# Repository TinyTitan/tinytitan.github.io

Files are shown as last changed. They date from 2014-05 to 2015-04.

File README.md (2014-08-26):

### Tiny Titan
Tiny Titan is a sub-$1,000 classroom supercomputer designed to teach aspiring scientists the basics of parallel computing. Unlike modern desktops and laptops that hide parallelism from the user, Tiny Titan makes parallel concepts explicit.

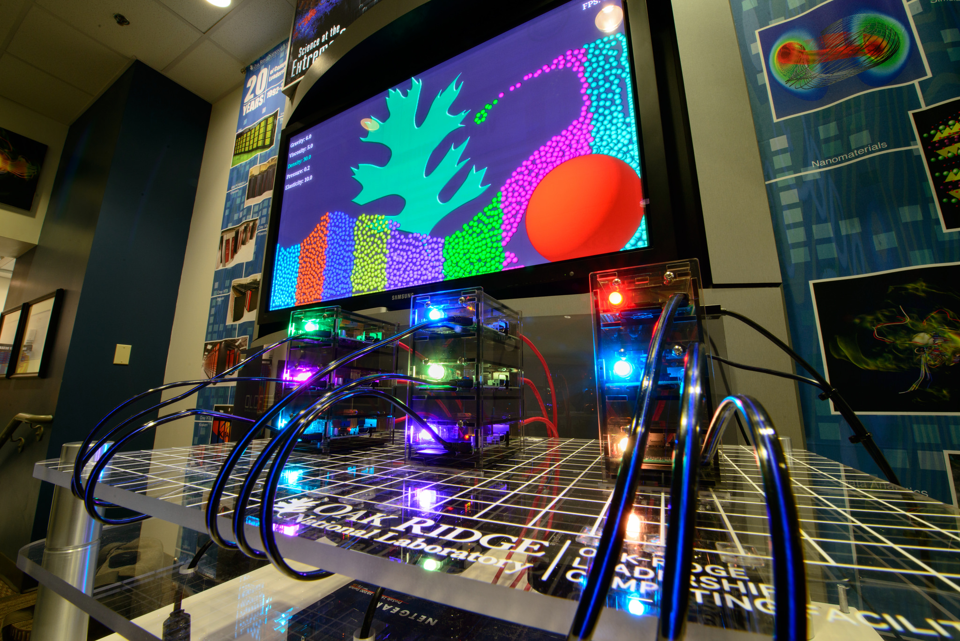
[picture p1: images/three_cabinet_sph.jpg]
SPH


## Software
Tiny Titan features a cornucopia of interactive parallel computing demonstrations and exercises. Some of these are available below:
* [Interactive Fluid Mechanics](https://github.com/TinyTitan/SPH)
* [PiBrot Race](https://github.com/TinyTitan/PiBrot)

## Build your Own
You can build and program your own Tiny Titan using the plans and parts lists available here:

* [9 x RASPBERRY-PI  RASPBERRY-PI/8GB-USD  MODEL B - 8GB SDCard W/ NOOBS PRE-INSTALLED](http://www.newark.com/raspberry-pi/raspberry-pi-8gb-usd/model-b-8gb-sdcard-w-noobs-pre/dp/04X5042)
* [9 x Flowing Effect MicroUSB Data+Charging Cable - Black w/Aqua EL](http://www.adafruit.com/products/1233)
* [9 x 2ft Flat Cat 5 100Mb Ethernet Cable](http://www.newegg.com/Product/Product.aspx?Item=N82E16812422526)
* [1 x Microsoft Xbox 360 Wireless Controller for Windows](http://www.amazon.com/Microsoft-Xbox-Wireless-Controller-Windows/dp/B004QRKWKQ/)
* [1 x BlueRigger High Speed HDMI to DVI Adapter Cable](http://www.amazon.com/BlueRigger-High-Speed-Adapter-Cable/dp/B005LJQO9G/)
* [1 x 18-8 Stainless Steel Socket Cap Screw, Button Head, Internal Hex Drive, Meets ISO 7380, 16mm Length, Fully Threaded, M3-0.5 Metric Coarse Threads (Pack of 100)](http://www.amazon.com/gp/product/B005E00BN2/)
* [1 x Steel Hex Nut, M3-0.5 Threads, Made in US (Pack of 100)](http://www.amazon.com/gp/product/B000NBIH92/)
* [3 x Plugable 7 Port High Speed USB 2.0 Hub with 3A Power Adapter](http://www.amazon.com/gp/product/B003Z4G3I6/)
* [1 x NETGEAR ProSAFE 16-Port Fast Ethernet Desktop Switch (FS116)](http://www.amazon.com/NETGEAR-ProSAFE-16-Port-Ethernet-Desktop/dp/B000063UZW/)

The final part is the laser cut acrylic cabinets. We recommend ordering from [Ponoko](http://www.ponoko.com). They allow you to upload svg files and have materials laser cut. Our design is an upright cabinet version of this [excellent Raspberry Pi Enclosure](http://www.thingiverse.com/thing:25100) by [builttospec](http://www.thingiverse.com/builttospec), and is likewise available under the [CC BY-SA 3.0](http://creativecommons.org/licenses/by-sa/3.0). You can download [SketchUp](http://www.sketchup.com) and [Ponoko](https://www.ponoko.com/) compatible svg files of our model here:

- [tinytitan_assembled_model.skp](http://tinytitan.github.io/downloads/tinytitan_assembled_model.skp)
- [tinytitan_flattened_parts.skp](http://tinytitan.github.io/downloads/tinytitan_flattened_parts.skp)
- [tinytitan_p3_inkscape_fixed.svg](http://tinytitan.github.io/downloads/tinytitan_p3_inkscape_fixed.svg)

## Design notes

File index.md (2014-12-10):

---
layout: page
title: Tiny Titan
description: "A sub-$1,000 classroom supercomputer"
modified: 2014-05-09
tags: [hardware]
image:
  feature: leadership_glamour_shot-2.jpg
  credit: Adam Simpson
  creditlink: http://olcf.ornl.gov
comments: false
share: true
---

Tiny Titan is a $1,000 classroom supercomputer designed to teach aspiring scientists the basics of parallel computing. Unlike modern desktops and laptops that hide parallelism from the user, Tiny Titan makes parallel concepts explicit.

SPH

## Software

Tiny Titan features interactive simulations that showcase the basic concepts of parallel computing. An Xbox controller allows students to explore load-balancing and communication by directing the simulation in real-time. Each of these simulations are freely available on our [GitHub](https://github.com/tinytitan).

## Build your Own

You can build and program your own Tiny Titan using the plans and parts lists available here:

| Quantity&nbsp; | Item |
| :---: | :--- |
| 9 | [Raspberry Pi Model B+ with 8GB Micro SD Card](http://www.newark.com/raspberry-pi/raspberry-modb-8gb-usd/raspberry-pi-model-b-8gb-micro/dp/68X0156) |
| 9 | [Animated Power Cables](http://www.adafruit.com/products/1233) |
| 9 | [USB LED Lights](http://buy.thingm.com/blink1) |
| 3 | [USB Power Hub](http://www.amazon.com/gp/product/B003Z4G3I6/) | 
| 3 | [Stackable Raspberry Pi B+ Case (Base)](http://www.amazon.com/Stackable-Case-Raspberry-Pi-Model/dp/B00M15N06I/) | 
| 6 | [Stackable Raspberry Pi B+ Case (Additional Layer)](http://www.amazon.com/Stackable-Raspberry-Pi-Case-Additional/dp/B00K5JKHUY/) | 
| 2 | [5 pack, 3ft Flat Ethernet Cables](http://www.amazon.com/Cable-Matters-5-Pack-Snagless-Ethernet/dp/B00E5I7UF6/) |
| 1 | [Wireless Microsoft Xbox 360 Controller](http://www.amazon.com/Microsoft-Xbox-Wireless-Controller-Windows/dp/B004QRKWKQ/) |
| 1 | [HDMI to DVI Adapter](http://www.amazon.com/BlueRigger-High-Speed-Adapter-Cable/dp/B005LJQO9G/) |
| 1 | [16-Port Ethernet Switch](http://www.amazon.com/NETGEAR-ProSAFE-16-Port-Ethernet-Desktop/dp/B000063UZW/) |
{: rules="groups"}

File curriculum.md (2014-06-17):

---
layout: page
title: Curriculum
permalink: /curriculum/
description: "An ideal platform for HPC education"
modified: 2013-05-31
category: articles
tags: [sample post]
image:
  feature: IMG_20140507_095849.jpg
comments: true
share: true
---

Comming soon!

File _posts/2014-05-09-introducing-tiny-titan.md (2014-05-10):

---
layout: post
title: Introducing Tiny Titan
description: "Just about everything you'll need to style in the theme: headings, paragraphs, blockquotes, tables, code blocks, and more."
modified: 2014-05-09
tags: [hardware]
image:
  feature: IMG_20140507_095849.jpg
comments: false
share: true
---

Tiny Titan is a sub-$1,000 classroom supercomputer designed to teach aspiring scientists the basics of parallel computing. Unlike modern desktops and laptops that hide parallelism from the user, Tiny Titan makes parallel concepts explicit.

SPH

## Software

Tiny Titan features a cornucopia of interactive parallel computing demonstrations and exercises. Some of these are available below:

* [Interactive Fluid Mechanics](https://github.com/adamsimpson/SPH)
* [PiBrot Race](https://github.com/AdamSimpson/Mandelbrot)

## Build your Own

You can build and program your own Tiny Titan using the plans and parts lists available here:

| Quantity&nbsp; | Item |
| :---: | :--- |
| 9 | [RASPBERRY-PI  RASPBERRY-PI/8GB-USD  MODEL B - 8GB SDCard W/ NOOBS PRE-INSTALLED](http://www.newark.com/raspberry-pi/raspberry-pi-8gb-usd/model-b-8gb-sdcard-w-noobs-pre/dp/04X5042) |
| 9 | [Flowing Effect MicroUSB Data+Charging Cable - Black w/Aqua EL](http://www.adafruit.com/products/1233) |
| 9 | [2ft Flat Cat 5 100Mb Ethernet Cable](http://www.newegg.com/Product/Product.aspx?Item=N82E16812422526) |
| 1 | [Microsoft Xbox 360 Wireless Controller for Windows](http://www.amazon.com/Microsoft-Xbox-Wireless-Controller-Windows/dp/B004QRKWKQ/) |
| 1 | [BlueRigger High Speed HDMI to DVI Adapter Cable](http://www.amazon.com/BlueRigger-High-Speed-Adapter-Cable/dp/B005LJQO9G/) |
| 1 | [18-8 Stainless Steel Socket Cap Screw, Button Head, Internal Hex Drive, Meets ISO 7380, 16mm Length, Fully Threaded, M3-0.5 Metric Coarse Threads (Pack of 100)](http://www.amazon.com/gp/product/B005E00BN2/) |
| 1 | [Steel Hex Nut, M3-0.5 Threads, Made in US (Pack of 100)](http://www.amazon.com/gp/product/B000NBIH92/) |
| 3 | [Plugable 7 Port High Speed USB 2.0 Hub with 3A Power Adapter](http://www.amazon.com/gp/product/B003Z4G3I6/) |
| 1 | [NETGEAR ProSAFE 16-Port Fast Ethernet Desktop Switch (FS116)](http://www.amazon.com/NETGEAR-ProSAFE-16-Port-Ethernet-Desktop/dp/B000063UZW/) |
{: rules="groups"}

The final part is the laser cut acrylic cabinets. We recommend ordering from [Ponoko](http://www.ponoko.com). They allow you to upload svg files and have materials laser cut. Our design, available [here](https://raw.github.com/olcf/tinytitan/master/images/tinytitan_p3_inkscape_fixed.svg), is an upright cabinet version of this [excellent Raspberry Pi Enclosure](http://www.thingiverse.com/thing:25100) by [builttospec](http://www.thingiverse.com/builttospec), and is likewise available under the [CC BY-SA 3.0](http://creativecommons.org/licenses/by-sa/3.0).
Below is just about everything you'll need to style in the theme. Check the source code to see the many embedded elements within paragraphs.

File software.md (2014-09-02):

---
layout: page
title: Software Setup
permalink: /software/
modified: 2013-05-31
category: articles
comments: true
share: true
---

<hr />

## TinyTitan setup

The OLCF has created a set of simple to use scripts to guide you through setting up your own TinyTitan. Once TinyTitan has been setup you will be ready to run the demo software

### Requirements

- At least two Raspberry Pis running the Raspbian distribution
- A network router or switch to connect the Pis to
- An active internet connection

### Step One
Step one will update each Raspberry Pi and configure the name and network settings. To start connect each Pi that will be part of the TinyTitan cluster to an active internet connection. Download the initial setup script and run it in a terminal as such:

~~~~~~
$ curl -kfsSLO https://raw.github.com/TinyTitan/TinySetup/master/pi_setup.sh
~~~~~~
~~~~~~
$ bash pi_setup.sh
~~~~~~

When prompted for the node number start at 1 and incriment to the total number of Raspberry Pi nodes.

### Step Two
With step one completed on all nodes connect each node to the router or switch. On the Pi that was given a node number of 1 login and download/run the second script:

~~~~~~
$ git clone https://github.com/TinyTitan/TinySetup.git
~~~~~~
~~~~~~
$ cd TinySetup
~~~~~~
~~~~~~
$ bash pi_post_setup.sh
~~~~~~

### Step Three
Your TinyTitan unit should now be ready to go. Checkout the TinySPH and PiBrot examples available through the TinyTitan repo.

## TinySPH
TinySPH is a parallel 2D Smoothed Particle Hydrodynamics(SPH) code, designed to run in real time on the Oak Ridge Leadership Computing Facility's "Tiny Titan" Raspberry Pi cluster. This application was designed to demonstrate distributed computing concepts and while it works best in a distributed environment it is possible to run on a shared memory system such as a single multicore processor. Although the code is designed for Tiny Titan it should, perhaps with some small build tweaks, compile and run on various flavors of Linux and OS X. The code makes use of MPI for distributed computing and requires at least two mpi processes(1 render, 1 compute).

SPH Screenshot

For full details please see the [TinySPH github page](https://github.com/TinyTitan/SPH)

# PiBrot
PiBrot is a parallel Mandelbrot set race. The screen is divided in half vertically with one MPI task drawing the left side image and an identical image being drawn on the right side with N-2 MPI tasks, where N is the total number of MPI tasks.

Final Screenshot

For full details please see the [PiBrot github page](https://github.com/TinyTitan/PiBrot)

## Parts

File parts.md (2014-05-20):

---
layout: page
title: Parts
permalink: /parts/
description: "Just about everything you'll need to style in the theme: headings, paragraphs, blockquotes, tables, code blocks, and more."
modified: 2013-05-31
category: articles
tags: [sample post]
image:
  feature: leadership_glamour_shot.jpg
  credit: Adam Simpson
  creditlink: http://olcf.ornl.gov
comments: true
share: true
---

Below is just about everything you'll need to style in the theme. Check the source code to see the many embedded elements within paragraphs.

# Heading 1

## Heading 2

### Heading 3

#### Heading 4

##### Heading 5

###### Heading 6

### Body text

Lorem ipsum dolor sit amet, test link adipiscing elit. **This is strong**. Nullam dignissim convallis est. Quisque aliquam.

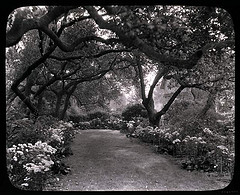
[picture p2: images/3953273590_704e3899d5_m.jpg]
Smithsonian Image

{: .pull-right}

*This is emphasized*. Donec faucibus. Nunc iaculis suscipit dui. 53 = 125. Water is H<sub>2</sub>O. Nam sit amet sem. Aliquam libero nisi, imperdiet at, tincidunt nec, gravida vehicula, nisl. The New York Times <cite>(That’s a citation)</cite>. <u>Underline</u>. Maecenas ornare tortor. Donec sed tellus eget sapien fringilla nonummy. Mauris a ante. Suspendisse quam sem, consequat at, commodo vitae, feugiat in, nunc. Morbi imperdiet augue quis tellus.

HTML and <abbr title="cascading stylesheets">CSS<abbr> are our tools. Mauris a ante. Suspendisse quam sem, consequat at, commodo vitae, feugiat in, nunc. Morbi imperdiet augue quis tellus. Praesent mattis, massa quis luctus fermentum, turpis mi volutpat justo, eu volutpat enim diam eget metus.

### Blockquotes

> Lorem ipsum dolor sit amet, test link adipiscing elit. Nullam dignissim convallis est. Quisque aliquam.

## List Types

### Ordered Lists

1. Item one
   1. sub item one
   2. sub item two
   3. sub item three
2. Item two

### Unordered Lists

* Item one
* Item two
* Item three

## Tables

| Header1 | Header2 | Header3 |
|:---|:---:|---:|
| cell1 | cell2 | cell3 |
| cell4 | cell5 | cell6 |
|----
| cell1 | cell2 | cell3 |
| cell4 | cell5 | cell6 |
|=====
| Foot1 | Foot2 | Foot3
{: rules="groups"}

## Code Snippets

Syntax highlighting via Pygments

{% highlight css %}
#container {
  float: left;
  margin: 0 -240px 0 0;
  width: 100%;
}
{% endhighlight %}

Non Pygments code example

    <div id="awesome">
        <p>This is great isn't it?</p>
    </div>

## Buttons

Make any link standout more when applying the `.btn` class.

<div markdown="0"><a href="#" class="btn">This is a button</a></div>

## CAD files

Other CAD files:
downloads/tinytitan_assembled_model.skp
downloads/tinytitan_flattened_parts.skp

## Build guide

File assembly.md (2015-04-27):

---
layout: page
title: Assembly
permalink: /assembly/
description: "Just about everything you'll need to style in the theme: headings, paragraphs, blockquotes, tables, code blocks, and more."
modified: 2013-05-31
category: articles
comments: true
share: true
---

A complete reference for Tiny Titan construction is available here: [Tiny Titan Build Instructions](http://tinytitan.github.io/downloads/TinyTitanBuildGuide.pdf)

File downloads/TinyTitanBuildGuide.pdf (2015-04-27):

# Build Guide for TinyTitan with SPH

Date:

April

30,

2015
Next

Planned

Update:

Summer

2015

Notes

Before

Beginning

Your

Build

TinyTitan

and

This

Guide
TinyTitan

is

a

mini

model-‐supercomputer

originally

designed

and

built

to

demonstrate
principles

of

supercomputing

to

visitors,

young

and

old,

at

the

Oak

Ridge

Leadership
Computing

Facility

(Oak

Ridge

National

Laboratory,

TN).

Constructed

from

commodity
parts

and

the

popular

raspberry-‐pi,

TinyTitan

has

grown

from

a

single

model

living

at

Oak
Ridge

National

Laboratory

into

an

idea

that

can

be

realized

by

others

and

shared

in

new
spaces.
This

guide

is

motivated

by

the

growing

number

of

do-‐it-‐yourselfers

and

tech-‐adventurous
educational

communities

interested

in

building

and

designing

their

own

TinyTitan.

The
goal

of

this

guide

is

to

provide

a

basic

overview

and

instruction

set

for

building

your

own
TinyTitan.

In

making

this

guide,

we

have

tried

to

include

the

important

steps

and

address
key

challenges; however

this

guide

is

not

comprehensive.

Both

TinyTitan

and

this

guide

are
a

continuing

work

in

progress.
Building

TinyTitan

will

require

a

do-‐it-‐yourself

spirit:

the

patience

to

problem-‐solve

(and
forgive

the

shortcomings

of

this

guide!),

the

willingness

to

research,

and

the
resourcefulness

to

find

help

from

others

when

needed.

We

hope

it

is

a

fun

and

rewarding
challenge!
We

are

very

excited

and

supportive

of

new

builders.

If

you

are

looking

for

support,

we
rarely

can

help

directly,

but

we

do

recommend:
- Engaging

with

other

builders

in

your

social

network
- Contacting

a

local

hackerspace

community

(these

groups

are

usually

very

happy

to
help!)
- Join

us

on

Github

and

post

to

the

community:

https://tinytitan.github.io

Background

Material
- If

you’re

new

to

raspberry-‐pis,

there

are

many

online

resources.

One

place

to

start

is
to

order

a ‘raspberry

pi

starter

kit’

and/or

a

guidebook.

We

happen

to

like

this

one
(but

no

official

endorsements):

‘Getting

Starting

with

Raspberry

Pi

(Make:

Projects)’
:

http://www.amazon.com/Getting-‐Started-‐Raspberry-‐Pi-‐Make/dp/1449344216/
- Some

familiarity

with

UNIX/LINUX

environments

is

strongly

recommended.

If

this

is
your

first

exposure

to

these

environments,

we

suggest

you

start

with

1

raspberry

pi
and

play

around

until

you

feel

comfortable.

Contents
Notes

Before

Beginning

Your
TinyTitan

and

This
Background
A.

Parts

and
Main
Parts

for

Programmable
Additional
B.

Basic

Set-‐up

of

Your

Raspberry
Powering

On

Your
Common
Install

the

Operating
Bare

Basics

of

Getting

Around

Your
C.

Connect

to

the
D.

Download

Packages

From
Common
E.

Connect

TinyTitan
F.

Run
G.

LED
USB-‐connected
GPIO

pin-‐connected
Connecting

LEDs

via

pre-‐made

pin
You

will

Description

of

Github

A. Parts

and

Examples

Below

is

a

table

of

parts

with bit.ly

links

to examples

for

each

part.

The

examples

are

not
endorsements,

guarantees,

or

<insert

here

every

other

form

of

disclaimer!>.

They

are
meant

to

provide

a

specific

example

of

the

part.
Main

Components

# | Part | Notes | Link: https://bit.ly/

2 -‐ 9 | raspberry-‐pi model B (or B+) | Available from many retailers: e.g. Amazon, Micro Center | ExampleParts_pi
2 -‐ 9 | SD cards with NOOBS (or Raspbian OS) pre-‐installed | These may come with your pis, if not, order separate. | ExampleParts_SD
1 | Ethernet Switch | Switch must have at least as many ports as you have pis | ExampleParts_switch
2-‐9 | Ethernet cable | One for each pi
1-‐3 | USB chargers | We suggest a charger using 4amps or or more. | ExampleParts_usbCharger
2-‐9 | USB to micro-‐ usb charging cord | One per pi. You can buy regular or light-‐up power cords. | ExampleParts_usbCord
1 | XBox wireless controller with transceiver | You can also use a wired controller. | ExampleParts_Xbox

Parts

for

Programmable

LEDs
TinyTitan

and

SPH

take

advantage

of

programmable

LEDs

to

visually

connect

each

pi

to

the
job

it

is

running.

SPH

will

run

without

LEDs

installed,

but

we

highly

recommend

including
them.

This

guide

has

two

build

options

for

the

LEDs.
[1]

USB

powered

LEDS

-‐ the

simple

but

more

costly

option.
[2]

GPIO

LEDs

-‐ cheap

option,

but

more

time

and

effort

to

install.

See

“Installing

LED’s”

section

for

other

parts

you

may

wish

to

buy.

# | Part | Notes | Link https://bit.ly/

2 -‐ 9 | USB programmable LED
1 | Daisy chain programmable LED | You can probably find this from other sellers | ExampleParts_LEDs

Additional Parts
Other

parts

you

will

need

for

TinyTitan

include:
- Monitor

(or

television)

-‐ to

see

TinyTitan

output
- Cord

to

connect

TinyTitan

to

your

monitor

-‐Raspberry

Pis use

HDMI

for

video
output.

A

modern

monitor/tv

is

likely

to

have

HDMI

or

DVI

input.

You

can

find

HDMI
to

HDMI

or

HDMI

to

DVI

cables

at

most

electronics

stores.
- Power

strip/

surge

protector.

TinyTitan

needs

more

than

one

outlet.

We

strongly
suggest

including

a

power

strip/

surge

protector

as

art

of

your

TinyTitan.
- Keyboard

with

usb

connector
- Mouse

with

usb

connector
- Wi-‐Fi adaptor

(recommended)

OR

Ethernet cable

-‐ you

will

need

to

be

able

to
connect

each

raspberry

pi

to

the

internet.

For

this

install,

you

only

ever

need

to
connect

one

pi

at

a

time

to

the

internet.

You

can

use

an

Ethernet cable

from

the

parts
list

above,

but

they

might

be

too

short

for

convenience.

B.

Basic

Set-‐up

of Your

Raspberry

Pi

The

following

steps

assume

a

new

raspberry-‐pi

and

a

new

SD

card

with

no

operating
system

installed

but

with

NOOBS.

If

you

are

new

to

raspberry-‐pis,

you

will

probably
want/need

to

supplement

with

other

materials.

There

are

many

online

(and

more
detailed!)

resources

for

these

basic

steps.
Powering

On

Your

Pi
1. Insert

SD

card

into

SD

slot.
2. Connect

pi

to

monitor

via

HDMI

port.
3. Connect

keyboard

to

pi

via

USB

port.
4. Connect

pi

to

power.

Pis

are

powered

via

the

micro-‐USB

port.

Connect

the

micro-‐
USB

power

cord

to

the

pi

and

to

the

USB

charger.
You

should

now

see

the

pi

output

as

it

boots

on

your

monitor.
Common

troubleshooting
- Loose

SD

cards

are

a

number

1

source

of

problems.

Unplug

your

pi

and

give

your

SD
card

an

extra

push.
- Check

your

monitor

and

pi

are

both

connected

to

a

power

supply.
- Check

your

monitor/tv

input

is

on

the

correct

input.

Install

the

Operating

System
NOOBS

will

have

several

OS

options.

Follow

the

on-‐screen

instructions

for

installing
Rasbian

O.S.

If

you

get

stuck,

check

online

for

help.

Bare

Basics

of

Getting

Around

Your

Pi
Refer

to

other

resources

for

more

details.

But

the

following

are

the

bare

basics.
- The

default

login

name

is

“pi”

(no

quotes).
- The

default

password

is

“raspberry”

(no

quotes).

TinyTitan

installation

assumes
‘raspberry’

is

password.

Do

not

Change!
- To

start

the

GUI

that

comes

with

your

pi,

type

in

the

command

line:
$ startx
- To

shutdown

your

pi,

type

in

the

command

line:
$ sudo shutdown -h now

C.

Connect

to

the

Internet

You

must

be

able

to

connect

each

pi

to

the

internet.

To

physically

connect,

connect

through
direct

Ethernet cord

OR

plug

in

Wi-‐Fi adapter

into

raspberry

pi

USB.

After

the

pi

is
physically

connected

via

Ethernet or

Wi-‐Fi adapter,

you

may

need

to

adjust

settings

so

the

pi

can

‘see’

the

internet.

For

users

less

familiar

with

UNIX/LINUX,

this

is

most

easily

done
through

the

GUI.

Please

see

other

resources

for

help

with

this

step.

D.

Download

Packages

From

Github

There

are

two

install

scripts

for

TinyTitan located

at

https://tinytitan.github.io.

One

script
pi_setup.sh ,

you

will

download

and

run

on

each

pi.

The

second

script,

pi_post_setup.sh you
will

download

and

run

on

only

the

master

pi (pi1).

Information

on

each

script

is

in

the
appendix.
1. Choose

one

pi

to

be

the

master

node.

This

is

‘pi1’.

Set

pi1

aside.
2. On

all

pis

EXCEPT

pi1
i. Connect

pi

to

monitor,

keyboard,

and

internet.

The

following

steps

are
performed

in

the

command

line.
ii. Make

sure

you

are

in

the

home

directory

by

typing

into

the

command

line:

$ cd ~
iii. Backup

the

file

/etc/network/interfaces by

typing

into

the

command

line:

$ sudo cp /etc/network/interfaces /etc/network/interfaces_backup
iv. Download

pi_setup.sh by

typing

into

the

command

line:

$ curl –kfsSLO https://raw.github.com/TinyTtian/TinySetup/master/pi_setup.sh
v. Run

the

pi_setup.sh by

typing

into

the

command

line:

$ bash ~/pi_setup.sh
vi. When

prompted

for

the

node

number,

start

with

‘2’.

For

each

new

pi,

increase
the

number.
vii. When

complete,

if

necessary,

shutdown

pi

and

disconnect

from

internet,
monitor,

and

keyboard

to

allow

the

next

pi

to

connect.
viii. Suggestion:

using

a

small

sticky

label,

label

the

SD

card

with

its’

corresponding
number

from

step

’vi’:

‘2’,

‘3’

etc.
3. Connect

pi1

(master

node)

to

the

internet,

monitor,

and

keyboard
i. Make

sure

you

are

in

home

directory

by

typing:

$ cd ~
ii. Backup

the

file

/etc/network/interfaces

by

typing

into

the

command

line:

$ sudo cp /etc/network/interfaces /etc/network/interfaces_backup
iii. Download

pi_setup.sh by

typing

into

the

command

line:

$ curl –kfsSLO https://raw.github.com/TinyTtian/TinySetup/master/pi_setup.sh
iv. Download

TinySetup

with

pi_post_setup.sh script:

$ git clone https://github.com/TinyTitan/TinySetup.git

v. Run

pi_setup.sh by

typing

into

the

command

line:

$ bash ~/pi_setup.sh

vi. When

prompted

for

the

node

number,

enter

‘1’.

To

run

the

pi_post_setup.sh script on

pi1,

TinyTitan must

be

all

connected

together

(step

E).
Common

Troubleshooting
- Unable

to

connect

to

github

through

‘curl’

or

‘clone’
- Try

online

resources

or

find

a

friend

familiar

with

LINUX

and

github

to

help.
- Try

your

pi’s

internet

connection

to

download

from

Github via

web

browser
- Unable

to

connect

to

internet

AFTER

running

pi_setup.sh
After

running

pi_setup.sh,

your

pi

will

likely

not

be

able

to

connect

to

Wi-‐Fi or

internet
until

you

have

reinstated

the

original

/etc/network/interfaces

file.

This

file

was
overwritten

when

you

ran

the

pi_setup.sh script.

Fortunately,

you

made

a

backup

in
steps

2iii

and

3ii! Here

is

how

to

undo

it.
1. Backup

TinyTitan

/etc/network/interfaces file:

$ sudo cp /etc/network/interfaces /etc/network/interfaces_TinyTitan
2. Re-‐instate

network

backup

file:

$ sudo mv /etc/network/interfaces_backup /etc/network/interfaces
3. Restart

pi
4. Don’t

forget,

the

TinyTitan

interfaces

file

must

be

reinstated

for

the

pi
to

work

with

TinyTitan.

E.

Connect

TinyTitan

Together.

1. Connect

each

pi

to

the

Ethernet switchbox

using

the

Ethernet cables.
2. Connect

pi1

to

the

monitor/tv
3. Connect

pi1

to

keyboard

(and

mouse

if

desired).
4. Connect

each

pi

to

the

power

supply

(micro-‐USB)
5. Connect

Ethernet

switchbox

to

power

supply
6. In

command

line

of

pi1,

run

the

pi_post_setup.sh script:

$ cd ~/TinySetup
$ bash pi_post_setup.sh

F.

Run

SPH

Your

TinyTitan

is

ready (fingers

crossed!). To

test

TinyTitan

and

SPH

follow

these

steps:
1. Connect

the

xbox

controller

to

pi1

through

the

USB

port.
2. Hit

the

center

circle button

on

the

xbox

controller.

You

should

see

green

lights
moving

in

a

circular

pattern

around

the

large

center

button.
3. Setup the

xbox

interface.

Enter

the

home

directory

($

cd

~)

and

type:

$ sudo rmmod xpad
$ sudo xboxdrv --config~/SPH/controller_1.cnf --silent &
4. The

green

lights

on

the

xbox

controller

should

have

stopped

moving.

The

light
should

be

fixed

next

to

the

‘1’

marker

on

the

controller.
5. Run

SPH

by

typing

the

following

into

the

command

line.

Replace

‘9’

with

the

total
number

of

nodes,

including

pi1,

in

your

TinyTitan.

$ cd ~
$ mpirun –f ../mpihostfile –n 9 ../sph.out
6. Loading

SPH

can

take

a

minute

or

two,

but

it

should

start

running.
7. To

exit

the

SPH

game,

use

CTRL-‐C

Common

Troubleshooting
- SPH

doesn’t

run – a

few

common

problems
- Check

the

GPU

has 128

MB

of

memory:
1.

Open

raspberry

pi

configuration:

$ sudo raspi-config
2.

In

the

GUI,

select

‘Advanced

Options’

-‐>

‘Memory

Split’.
3. Enter

128

for

GPU.

Select

‘Ok’

-‐>

‘Finish’

-‐>

(would

you

like

to

reboot

now?)
‘Yes’
- Communication

error

to

the

pis
Try the

‘ping’

command

to

test

the

communication

between

pi1

and

each

pi.
If

you

find

the

trouble

pi,

likely

the

SD

card

is

loose.

Also

check

the

power

and
the

ethernet

cables

are

properly

in

place.
- Another

problem?

SPH

code

works

on

a

fresh

SD

card.

If

you

have

played
with

ssh passwords,

the

pi

password,

file

ownership

(e.g.

making

files

from
root),

then

SPH

may

not

run.

Try

wiping

the

SD

card,

re-‐installing

the

OS

and
installing

the

SPH

code.

You

can

also

do

this

by

ordering

a

new

SD

card.

We
hope

the

community

may

fix

some

of

these

bugs

in

the

future!

- The

xbox

controller

doesn’t

work
- Try

restarting

pi1

with

the

xbox

controller

in

a

different

usb

port.

Also,
unplug

unnecessary

usb

dongles

(e.g.

mouse).

- Not

as

fun,

but

you

can

run

SPH

with

some

basic

features

using

the

keyboard

G.

LED

Installation

The

Github

SPH

program supports

usb-‐connected

LEDs

OR

GPIO

pin-‐connected

LEDs.
USB-‐connected

LEDs
1. Connect

each

usb-‐LED

into

the

usb

port

for

each

pi.

Done!
GPIO

pin-‐connected

LEDs
There

are

several

ways

you

can

connect

GPIO

pin-‐connected

LEDs.

A

few

examples

include
[1]

wire-‐wrapping

(noooo!),

[2]

crimping

(impress

your

tech

savy

friends

with

your

ideal
choice!),

[3]

cheating

via

pre-‐made

female

pin-‐connectors,

wire-‐stripping,

and

soldering

(or
electrical

tape

and

watch

your

tech

savy

friends

cringe!).
From

experience,

choice

[3]

is

the

most

accessible

to

the

less

experienced

(and

method

of
choice

for

our

most

novice

author),

we

therefore

include

guidance

for

choice

[3].
Connecting

LEDs

via

pre-‐made

pin

connectors

You

will

need/want:
- pre-‐made

female

pin connectors

-‐ we

found

ours

in

MicroCenter
(e.g. bit.ly/ExampleParts_Fpin)
- wire

strippers
- solder

an

solder

iron

(else

electrical

tape,

but

the

connections

may

be

more
susceptible

to

breaking)
- heat shrink

wrap

(looks

nice)

or

electrical

tape

(not

as

nice).
Directions
Do

a

test

run

with

1

LED

first!
1. Identify

the

side

of

the

LED wires

that

connect

to

the

pins. The

LEDs

have
directionality!

You

must

connect

the

correct

side

of

the

LED

wires

to

the

GPIO pins.
To

determine

which

side,

look

at

the

daisy-‐chain

of

LEDs.

One

end

will

have

a

female
pin

connector

(it

will

look

like

you

could

just

plug

it

into

your

pi’s

GPIO

pins).

Call
this

end

the

left-‐hand-‐side.
2. Cut

your

LEDs

from

the

daisy

chain.

Take

the

left-‐most

LED

and

cut

the

wire

on

the
right-‐hand

side

of

the

LED

close

to

the

LED

itself.

Your

LED

should

now

be

free

from
the

daisy

chain.

The

LED

has

one

side

with

long-‐wires

sticking

out

(the

left-‐hand
side),

and

one

side

with

very

short

wires

(the

right

hand

side).

If

this

is

the

first

LED,
the

long-‐wires

will

still

be

attached

to

the

GPIO-‐pin

connector.

Cut

this

connector

so
you

just

have

the

LED

with

its’

wire.

3. Connect

each

LED

wire

to

a

female

pin-‐connector.

Please

use

online

resources

for
methods for

connecting

two

wires:

stripping,

twisting,

soldering

and

heat

shrink
wrapping.
4. Identify

LED

wires.

Your

LED

has

four

wires:

+5V,

Ground,

Data,

and

Clock.

Use

the
LED

manufacturer’s

specifications to

know

which

wire

color

corresponds

to

which
label

(+5V, Ground,

Data,

or

Clock).
5. Identify

GPIO

pins.

Using

manufacturer’s

specifications

to

identify

which

raspberry-‐
pi

GPIO

pins

corresponds

with

+5V,

Ground,

Data,

and

Clock.
6. Connect

LEDs

to

pi by

connecting

each

female

pin

connector

to

the

correct

male

pin
on

the

raspberry-‐pi,

one

LED

per

pi.

Appendix

Description

of

Github

Scripts

pi_setup.sh
The

primary

job

of

this

script

is:
- Update

your

pi

with

the

latest

available

configurations
- Install

packages

necessary

for

Tiny

Titan

including:
- parallel

programming

(mpich2)
- pi

to pi

communication via

ssh (sshpass)
- xbox

controller

(xboxdrv)
- Rename

pi
- Set

network

configurations

for

communication

via

the

Ethernet switch

pi_post_setup.sh
The

primary

job

of

this

script

is:
- Provide

pi1,

the

master

node,

with

a

list

of

IP addresses

for

each

pi

and
corresponding

pi

name.

This

information

is

written

to:

~/mpihostfile
- Provide

pi1,

master

node,

with

the

ssh

key

for

each

pi.

This

enables

pi1

to
communicate

with

each

pi

without

a

human

entering

passwords

each

time.

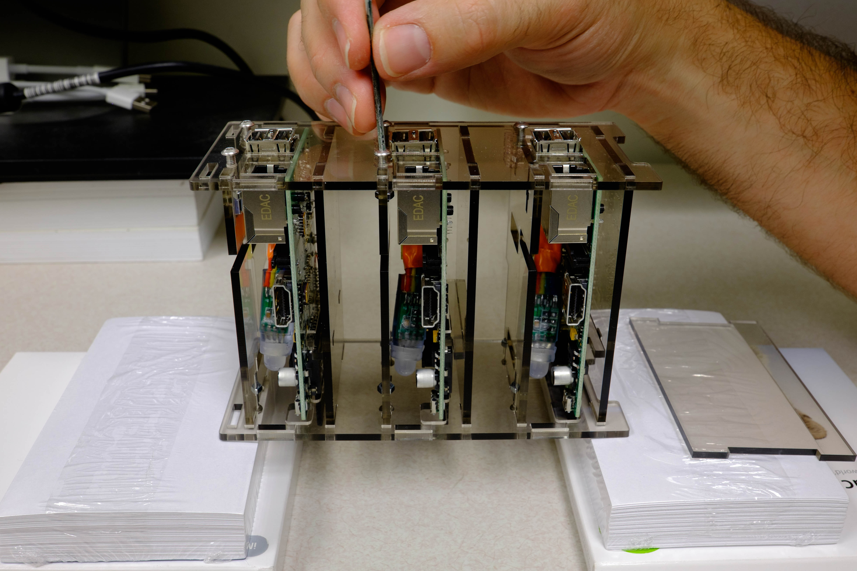
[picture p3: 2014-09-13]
images/Construction-v1/image25.jpg

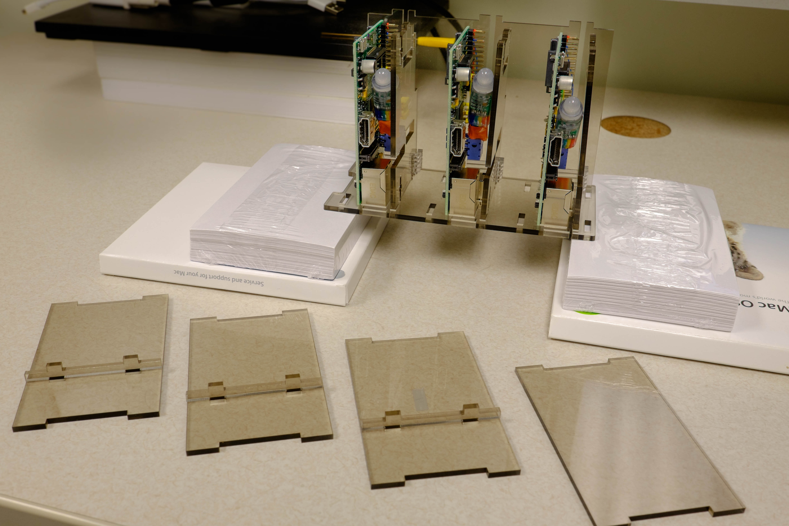
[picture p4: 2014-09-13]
images/Construction-v1/image11.jpg

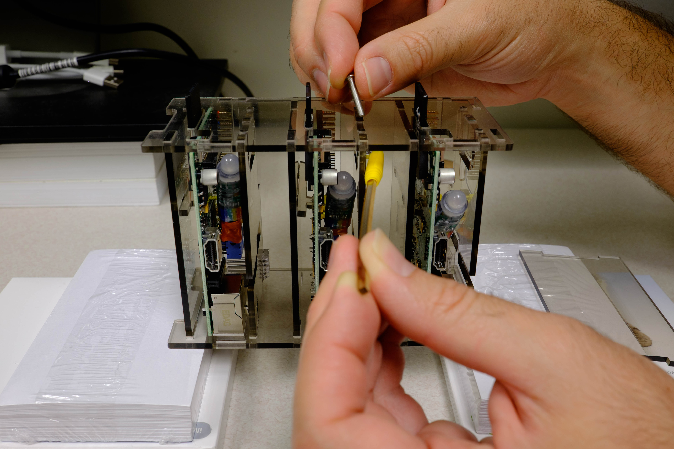
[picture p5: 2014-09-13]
images/Construction-v1/image17.jpg

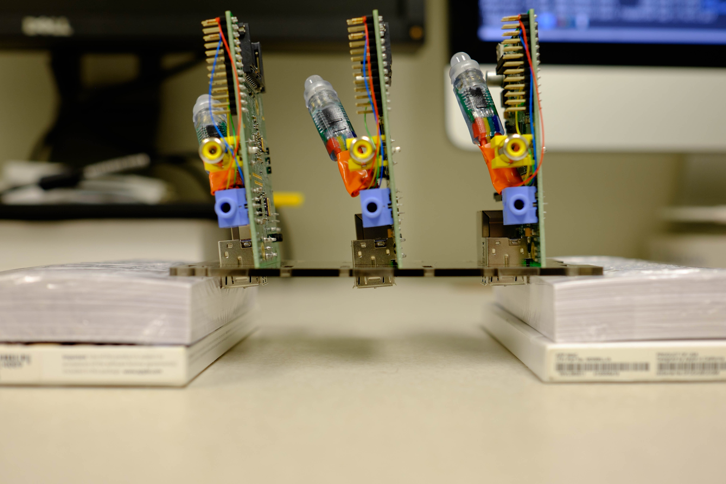
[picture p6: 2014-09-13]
images/Construction-v1/image5.jpg

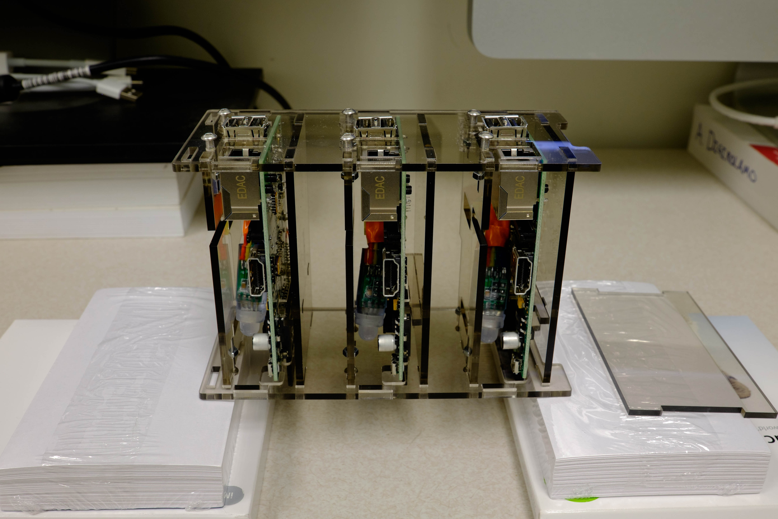
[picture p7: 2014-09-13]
images/Construction-v1/image26.jpg

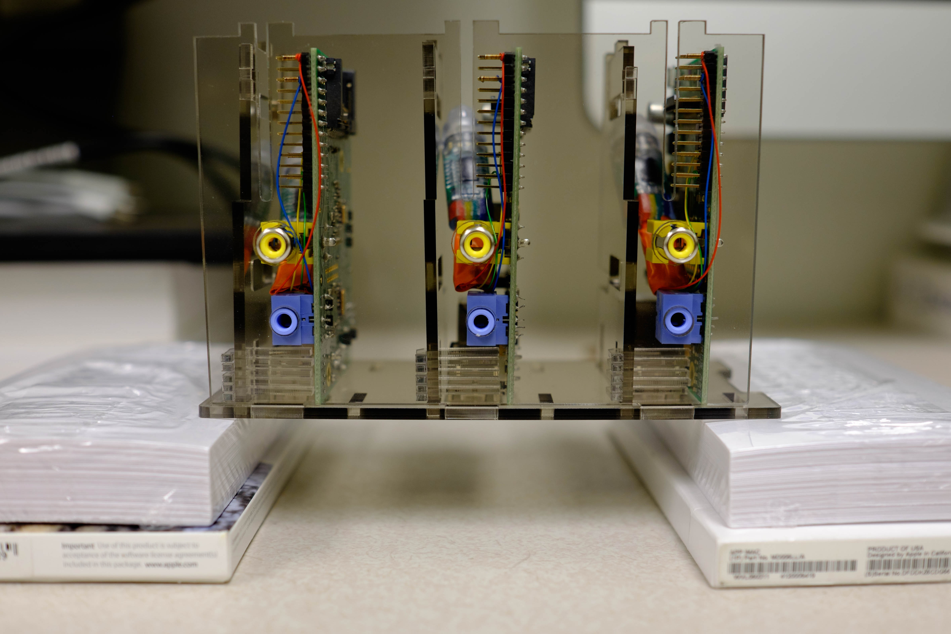
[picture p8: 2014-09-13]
images/Construction-v1/image9.jpg

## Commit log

2014-05-02 Add flat ethernet cable to parts list
2014-05-10 switched themes
2014-05-21 Need a curriculum page, parts can go under assembly
2014-06-21 added fixed tinytitan model files
    [tinytitan_assembled_model.skp, tinytitan_flattened_parts.skp]
2014-06-21 added download links for case model files
    fixes issue #1
2014-08-18 Replace out of stock red cables with blue ones
2014-08-18 added missing svg file for the case lightpipes
2014-09-13 Working on assembly
